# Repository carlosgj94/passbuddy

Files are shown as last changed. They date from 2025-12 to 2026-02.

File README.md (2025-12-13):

# Passbuddy — Hardware KeePass for ESP32-S3

Passbuddy is a no_std Rust firmware for the ESP32-S3 that acts like a USB keyboard (HID) to auto-type passwords stored in an on-device KeePass database. The database lives in flash and is encrypted with a software key derived from a user PIN plus the chip’s efuse keyslot 0 (unreadable externally), so secrets never leave the device.

## How It Works
- **Key derivation:** User PIN + IFUSE/HMAC using keyslot 0 → one-time KDF output (software key). The hardware root key never leaves the chip, and the PIN never leaves the device. The software key encrypts/decrypts the KeePass DB.
- **Usage model:** Plug the device; it enumerates as a USB keyboard. Enter PIN locally (buttons/rotary/etc). The DB decrypts on-device. When a login field is focused, the device types the selected password over USB keystrokes.
- **Security posture:** No cloud or sync. Flash theft is useless without the PIN and bypassing S3 anti-dump protections. Vendor compromise is irrelevant because secrets stay on hardware.

## Project Layout
- `src/bin/main.rs` — ESP-RTOS entrypoint; sets CPU clocks, HMAC peripheral, SPI2, and SSD1309 display; draws a simple `ratatui` list via `mousefood`; logs a heartbeat.
- `src/display.rs` — display helpers (`init_terminal`, `initial_state`, `draw_menu`).
- `src/display/ssd1309.rs` — SSD1309 SPI driver implementing `embedded-graphics` `DrawTarget` + framebuffer flush.
- `src/encryption.rs` — HMAC-based software key derivation (`derive_sw_key`).
- `build.rs` — adds linker scripts (`defmt.x`, `linkall.x`) and prints hints for missing symbols.
- `.cargo/config.toml` — targets `xtensa-esp32s3-none-elf`, sets `espflash` runner, enables `build-std` for `core`/`alloc`.

## Prereqs
- Rust toolchain channel `esp` (see `rust-toolchain.toml`); install Xtensa support via Espressif’s toolchain (e.g., `espup`).
- `espflash` installed and USB permissions set (dialout/uaccess on Linux).

## Build, Flash, and Dev
```bash
cargo build                 # dev build for ESP32-S3
cargo build --release       # size-optimized
cargo clippy --no-deps      # lint; keep warnings at zero
cargo run                   # flash + defmt monitor via espflash (device attached)
```
Notes: ensure only one serial/monitor session is open when flashing; replug USB if flashing stalls.

## Architecture Notes
- No_std + Embassy executor; heap set via `esp_alloc::heap_allocator!` in `main`.
- Display: SSD1309 over SPI2 (custom driver); UI rendered with `ratatui`/`mousefood`.
- HID keyboard output planned for password typing; input hardware for PIN entry is TBD.

## Status / Next Steps
- ✅ Display init and static menu render.
- ✅ Software key derivation helper using HMAC + RNG.
- ⏳ Implement PIN input, KeePass DB storage/crypto flow, HID keyboard typing, and runtime UI updates (via Embassy task).

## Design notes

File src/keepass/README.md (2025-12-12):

# KeePass v1 (KDB) File Format Reference

This document describes the full binary structure of a **KeePass v1 (.kdb)** database.  
It is tailored for implementors building parsers/writers (including embedded systems).

KeePass v1 is a flat, streaming binary format consisting of a plaintext header followed by an AES-encrypted payload containing groups and entries.

---

## 1. High-Level File Structure

```
+------------------------------+
|        HEADER (PLAINTEXT)    |
+------------------------------+
|     ENCRYPTED PAYLOAD        |
|     (AES-256-CBC)            |
|   +-----------------------+  |
|   | GROUP TABLE (N groups)|  |
|   +-----------------------+  |
|   | ENTRY TABLE (M entries)| |
|   +-----------------------+  |
|   | END MARKER             | |
|   +------------------------+ |
+------------------------------+
```

Groups and entries use the same TLV structure, but they appear in **separate sections**, and their counts are given in the header.

---

## 2. Header (Plaintext)

The header is unencrypted and always appears first.

```
MAGIC_1 (u32)               = 0x9AA2D903
MAGIC_2 (u32)               = 0xB54BFB66

VERSION (u32)               = (minor << 16 | major)
ENCRYPTION FLAGS (u32)
VERSION2 (u32)              = typically 0

MASTER SEED (16 bytes)
ENCRYPTION IV (16 bytes)

TRANSFORM SEED (32 bytes)
TRANSFORM ROUNDS (u32)

STREAM START BYTES (32 bytes)

GROUP COUNT (u32)           = number of groups N
ENTRY COUNT (u32)           = number of entries M
```

These counts determine how many groups and entries you must parse later.

---

## 3. Encrypted Payload (AES-256-CBC)

The payload is encrypted using:

```
AES_KEY = SHA256( master_seed || transformed_user_key )
```

Where `transformed_user_key` is produced by repeatedly encrypting the user key using AES-ECB for `TRANSFORM_ROUNDS`.

After decryption, the payload consists of:

```
[Group 1]
[Group 2]
...
[Group N]

[Entry 1]
[Entry 2]
...
[Entry M]

[Final End Marker]
```

---

## 4. TLV (Type-Length-Value) Encoding

Groups and entries share the same TLV encoding:

```
field_type : u16 (LE)
field_size : u32 (LE)
field_data : [field_size] bytes
```

Strings include a **null terminator** inside the field data.

Every group and entry ends with:

```
Type = 0xFFFF
Size = 0x00000000
```

---

## 5. Group Table (N Groups)

Parse **GroupCount** groups in order.

### Group Field Types

```
0x0001 → Group ID (u32)
0x0002 → Group Name (UTF-8, null-terminated)
0x0003 → Creation Time (packed time, 5 bytes)
0x0004 → Last Modification Time (packed time, 5 bytes)
0x0005 → Icon ID (u32)
0x0006 → Level (u16)
0xFFFF → End of Group
```

**Level** defines how groups are nested (indentation), not parent pointers.

---

## 6. Entry Table (M Entries)

After all groups are parsed, read **EntryCount** entries.

### Entry Field Types

```
0x0001 → UUID (16 bytes)
0x0002 → Group ID (u32)
0x0003 → Title (UTF-8, null-terminated)
0x0004 → Username (UTF-8)
0x0005 → Password (UTF-8)
0x0006 → URL (UTF-8)
0x0007 → Notes (UTF-8)

0x0008 → Creation Time (packed time, 5 bytes)
0x0009 → Last Modification Time (packed time, 5 bytes)
0x000A → Last Access Time (packed time, 5 bytes)
0x000B → Expiration Time (packed time, 5 bytes)
0x000C → Byte Description (UTF-8)
0x000D → Byte Data (raw bytes)

0xFFFF → End of Entry
```

Entries point to groups using `Group ID`.

---

## 7. End-of-Database Marker

After the last entry:

```
Type = 0xFFFF
Size = 0x00000000
```

This marker is required.

---

## 8. Parsing Procedure Summary

```
read header

for each group in 0..GroupCount:
    read TLV fields until type == 0xFFFF

for each entry in 0..EntryCount:
    read TLV fields until type == 0xFFFF

read final 0xFFFF database terminator
```

---

## 9. Notes for Implementors

- Group and entry TLV field types overlap; **context** (group section vs entry section) determines meaning.
- KeePass v1 stores timestamps as a packed 5-byte value (not Unix `time_t`).
- Strings are null-terminated inside the TLV binary.
- Adding or removing groups/entries requires rebuilding the entire payload; KDB is not a random-access format.

---

This reference is complete and suitable for building a KDB parser/writer from scratch.

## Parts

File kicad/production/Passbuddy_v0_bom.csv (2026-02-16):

Designator | Footprint | Quantity | Value | LCSC Part #
C1, C4, C5 | 0805 | 3 | 10uF 0805
C2 | 1206 | 1 | 22uF 1206
C3, C6 | 0402 | 2 | 100nF 0402
C7 | 0805 | 1 | 4.7uF 0805
D1, D2, D3 | 0603 | 3 | LED 0603 White
J1 | USB_C_Receptacle_HRO_TYPE-C-31-M-12 | 1 | USB_C_Receptacle_USB2.0_16P | C53207138
J2 | Tropic01_PinSocket | 1 | Conn_01x08_Socket
J3 | PinSocket_1x07_P2.54mm_Horizontal | 1 | Conn_01x07_Pin | C2897389
R1, R2, R3, R4, R5, R6 | 0402 | 6 | 5.1kΩ 0402
R7 | 0402 | 1 | 10kΩ 0402
S1 | XDCR_PEC11R-4220F-S0024 | 1 | PEC11R-4220F-S0024
SW2, SW3 | SW_SPST_B3U-1000P | 2 | SW_SPST | C720477
U1 | ESP32-S3-WROOM-1 | 1 | ESP32-S3-WROOM-1 | C2913202
U2 | SOT-223-3_TabPin2 | 1 | LD1117S33TR_SOT223 | C6186

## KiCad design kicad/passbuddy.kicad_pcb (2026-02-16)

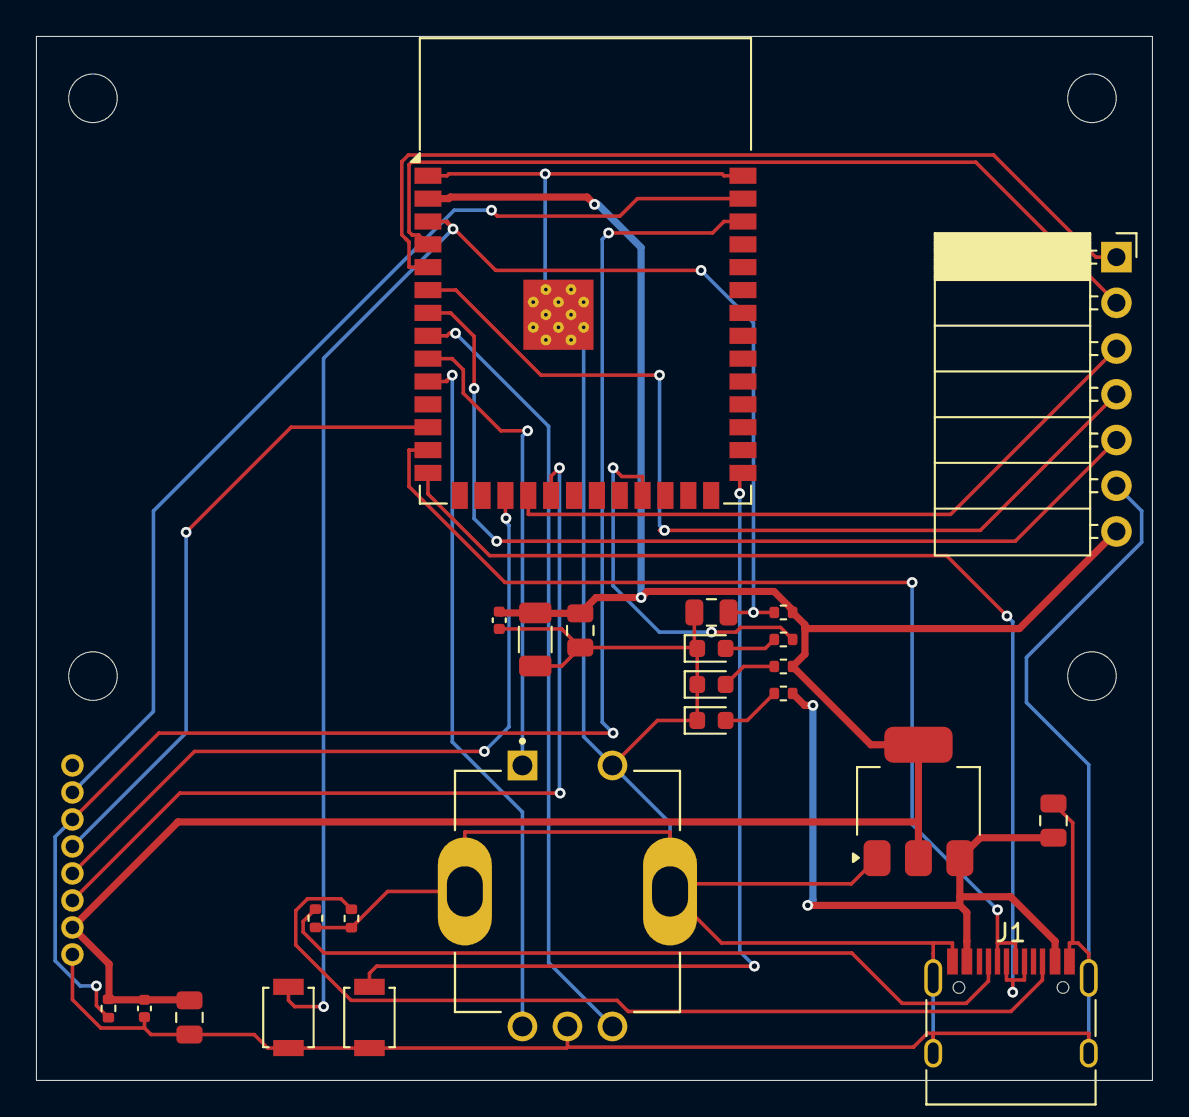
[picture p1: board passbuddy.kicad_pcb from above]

Board: 2 copper layers, 62.0 x 58.0 mm, 29 parts (0 on the bottom side), 26 nets.

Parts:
C1, C4, C5: 10uF 0805; C_0805_2012Metric
C2: 22uF 1206; C_1206_3216Metric
C3, C6: 100nF 0402; C_0402_1005Metric
C7: 4.7uF 0805; C_0805_2012Metric
D1, D2, D3: LED 0603 White; LED_0603_1608Metric
J1: USB_C_Receptacle_USB2.0_16P; USB_C_Receptacle_HRO_TYPE-C-31-M-12
J2: Conn_01x08_Socket; Tropic01_PinSocket
J3: Conn_01x07_Pin; PinSocket_1x07_P2.54mm_Horizontal
MountHole1, MountHole3, MountHole4: MountHole; MountingHole_2.7mm_M2.5
MountHole2: MountingHole_2.7mm_M2.5
R1, R2, R3, R4, R5, R6: 5.1kΩ 0402; R_0402_1005Metric
R7: 10kΩ 0402; R_0402_1005Metric
S1: PEC11R-4220F-S0024; XDCR_PEC11R-4220F-S0024
SW2, SW3: SW_SPST; SW_SPST_B3U-1000P
U1: ESP32-S3-WROOM-1
U2: LD1117S33TR_SOT223; SOT-223-3_TabPin2

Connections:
+3V3: C1.1, C2.1, C3.1, C6.1, C7.1, J2.7, J3.7, R4.2, R6.1, R7.2, U1.2 (3V3), U2.2 (VO)
+5V: C4.1, J1.A4 (VBUS), J1.A9 (VBUS), J1.B4 (VBUS), J1.B9 (VBUS), R5.1, U2.3 (VI)
CLK: J3.4, U1.6 (IO6)
CS: J3.3, U1.18 (IO10)
D+: J1.A6 (D+), J1.B6 (D+), U1.14 (USB_D+)
D-: J1.A7 (D-), J1.B7 (D-), U1.13 (USB_D-)
DC: J3.2, U1.4 (IO4)
DIN: J3.5, U1.7 (IO7)
EN: C5.1, R6.2, SW3.2 (B), U1.3 (EN)
GND: C1.2, C2.2, C3.2, C4.2, C5.2, C6.2, C7.2, D1.1 (K), D2.1 (K), D3.1 (K), J1.A1 (GND), J1.A12 (GND), J1.B1 (GND), J1.B12 (GND), J1.S1 (SHIELD), J2.8, J3.6, R1.2, R2.2, S1.2, S1.C (COM), S1.SH1 (SHIELD), S1.SH2 (SHIELD), SW2.1 (A), SW3.1 (A), U1.1 (GND), U1.40 (GND), U1.41 (GND), U2.1 (GND)
GPIO0: SW2.2 (B), U1.27 (IO0)
GPIO16: S1.1, U1.9 (IO16)
GPIO21: R3.1, U1.23 (IO21)
unnamed: D1.2 (A), R5.2
unnamed: D2.2 (A), R4.1
unnamed: D3.2 (A), R3.2
unnamed: J1.A5 (CC1), R1.1
unnamed: J1.B5 (CC2), R2.1
RST: J3.1, U1.5 (IO5)
RT_CLK: S1.A, U1.10 (IO17)
RT_DT: S1.B, U1.8 (IO15)
TROPIC_CLK: J2.4, U1.12 (IO8)
TROPIC_CS: J2.3, R7.1, U1.38 (IO2)
TROPIC_GPO: J2.2, U1.39 (IO1)
TROPIC_SDI: J2.6, U1.19 (IO11)
TROPIC_SDO: J2.5, U1.17 (IO9)

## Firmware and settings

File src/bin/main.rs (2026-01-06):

#![no_std]
#![no_main]
#![deny(
    clippy::mem_forget,
    reason = "mem::forget is generally not safe to do with esp_hal types, especially those \
    holding buffers for the duration of a data transfer."
)]

extern crate alloc;

mod usb_hid;

use defmt::info;
use embassy_executor::Spawner;
use embassy_time::{Duration, Timer};
use embedded_hal_bus::spi::ExclusiveDevice;
use esp_hal::delay::Delay;
use esp_hal::gpio::{Level, Output, OutputConfig};
use esp_hal::otg_fs::Usb;
use esp_hal::spi::{Mode as SpiMode, master::Config as SpiConfig, master::Spi};
use esp_hal::time::Rate;
use esp_hal::timer::timg::TimerGroup;
use esp_hal::{clock::CpuClock, hmac::Hmac};
use esp_storage::FlashStorage;
use passbuddy::app::AppState;
use passbuddy::keepass::KeePassDb;
use passbuddy::storage::layout::StorageLayout;
use passbuddy::storage::region::DataRegion;
use {esp_backtrace as _, esp_println as _};

use passbuddy::input::Inputs;
use passbuddy::{app, display};

// This creates a default app-descriptor required by the esp-idf bootloader.
// For more information see: <https://docs.espressif.com/projects/esp-idf/en/stable/esp32/api-reference/system/app_image_format.html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>
esp_bootloader_esp_idf::esp_app_desc!();

#[esp_rtos::main]
async fn main(spawner: Spawner) -> ! {
    // generator version: 1.0.1

    let config = esp_hal::Config::default().with_cpu_clock(CpuClock::max());
    let peripherals = esp_hal::init(config);

    esp_alloc::heap_allocator!(#[esp_hal::ram(reclaimed)] size: 73744);

    let timg0 = TimerGroup::new(peripherals.TIMG0);
    esp_rtos::start(timg0.timer0);

    info!("Embassy initialized!");

    // 1. Get the peripherals declared
    info!("Declared peripherals");
    let mut _hmac = Hmac::new(peripherals.HMAC);
    let spi = Spi::new(
        peripherals.SPI2,
        SpiConfig::default()
            .with_frequency(Rate::from_mhz(10))
            .with_mode(SpiMode::_0),
    )
    .unwrap()
    .with_sck(peripherals.GPIO6)
    .with_mosi(peripherals.GPIO7);
    let usb = Usb::new(peripherals.USB0, peripherals.GPIO20, peripherals.GPIO19);

    // 2. Let's initialize the display
    info!("Initializing display");
    let cs = Output::new(peripherals.GPIO10, Level::High, OutputConfig::default());
    let dc = Output::new(peripherals.GPIO4, Level::Low, OutputConfig::default());
    let reset = Output::new(peripherals.GPIO5, Level::High, OutputConfig::default());

    let spi_dev = ExclusiveDevice::new_no_delay(spi, cs).unwrap();
    let interface = display::ssd1309::SpiInterface::new(spi_dev, dc);
    let mut display = display::ssd1309::Ssd1309::new(interface, Some(reset));

    display
        .init(&mut Delay::new())
        .unwrap_or_else(|_| panic!("SSD1309 init failed"));

    let app_state = AppState::new();
    let mut terminal = app::init_terminal_with_flush(&mut display, |display| {
        display
            .flush()
            .unwrap_or_else(|_| panic!("SSD1309 flush failed"));
    });

    // 4. Let's initialize the storage
    info!("Initializing storage");
    let mut storage = FlashStorage::new(peripherals.FLASH);

    // Debug helper: wipe the storage layout sector. If enabled, keep it *before*
    // `run_healthcheck()` so the layout gets bootstrapped again.
    // StorageLayout::wipe_layout(&mut storage).unwrap();

    match StorageLayout::run_healthcheck(&mut storage) {
        Ok(_) => {
            info!("Storage found; good to read");
        }
        Err(_) => {
            // The decive needs to be writen
            info!("Storage not found; initializing");
            StorageLayout::bootstrap_storage_write(&mut storage)
                .expect("initial storage bootstraping error");
        }
    }

    let layout = StorageLayout::new(&mut storage);
    let magic_str = core::str::from_utf8(&layout.header.magic).unwrap_or("<invalid utf8>");
    info!("magic: {=str}", magic_str);

    // 5. Let's initialize the input devices
    info!("Setting the inputs");
    let mut inputs = Inputs::new(peripherals.GPIO17, peripherals.GPIO15, peripherals.GPIO16);
    //
    // 6. Get the key to decrypt the storage
    //
    // 7. Get the keepass groups
    let keepass_region = layout.region_handle(DataRegion::KeePassDb).unwrap();
    if !KeePassDb::check_if_exists(&mut storage, keepass_region).unwrap() {
        info!("Creating a new keepass");
        KeePassDb::initialize_db(&mut storage, keepass_region).unwrap();
    }

    info!("Indexing the keepass database");
    let kpdb = KeePassDb::new(&mut storage, keepass_region).unwrap();
    let mut app_state = app_state.with_kpdb(kpdb);

    usb_hid::spawn(&spawner, usb);

    info!("Starting the loop");
    const INPUT_TICK_MS: u64 = 2;
    const UI_TICK_MS: u64 = 50;
    let mut ui_elapsed_ms = 0u64;

    loop {
        Timer::after(Duration::from_millis(INPUT_TICK_MS)).await;
        let delta = inputs.poll_encoder_delta();
        if delta != 0 {
            app_state.apply_navigation(delta);
        }

        ui_elapsed_ms = ui_elapsed_ms.saturating_add(INPUT_TICK_MS);
        if ui_elapsed_ms >= UI_TICK_MS {
            ui_elapsed_ms = ui_elapsed_ms.saturating_sub(UI_TICK_MS);
            app_state.apply_navigation(0);

            if inputs.poll_button_pressed() {
                info!("Action button pressed");
                app_state.on_select(&mut storage);
            }

            app_state.on_tick(&mut storage);

            terminal
                .draw(|frame| app_state.draw_current_screen(frame))
                .expect("to draw");
        }
    }
}

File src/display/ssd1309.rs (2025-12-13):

use core::convert::Infallible;

use embedded_graphics::{
    geometry::Size,
    pixelcolor::BinaryColor,
    prelude::{DrawTarget, OriginDimensions, Pixel},
};
use embedded_hal::{delay::DelayNs, digital::OutputPin, spi::SpiDevice};

const WIDTH: usize = 128;
const HEIGHT: usize = 64;
const PAGES: usize = HEIGHT / 8;
const BUFFER_SIZE: usize = WIDTH * PAGES;

pub trait DisplayInterface {
    type Error;

    fn send_commands(&mut self, cmds: &[u8]) -> Result<(), Self::Error>;
    fn send_data(&mut self, data: &[u8]) -> Result<(), Self::Error>;
}

pub enum InterfaceError<SpiError, PinError> {
    Spi(SpiError),
    Pin(PinError),
}

pub struct SpiInterface<SPI, DC> {
    spi: SPI,
    dc: DC,
}

impl<SPI, DC> SpiInterface<SPI, DC> {
    pub fn new(spi: SPI, dc: DC) -> Self {
        Self { spi, dc }
    }

    pub fn release(self) -> (SPI, DC) {
        (self.spi, self.dc)
    }
}

impl<SPI, DC> DisplayInterface for SpiInterface<SPI, DC>
where
    SPI: SpiDevice<u8>,
    DC: OutputPin,
{
    type Error = InterfaceError<SPI::Error, DC::Error>;

    fn send_commands(&mut self, cmds: &[u8]) -> Result<(), Self::Error> {
        self.dc.set_low().map_err(InterfaceError::Pin)?;
        self.spi.write(cmds).map_err(InterfaceError::Spi)
    }

    fn send_data(&mut self, data: &[u8]) -> Result<(), Self::Error> {
        self.dc.set_high().map_err(InterfaceError::Pin)?;
        self.spi.write(data).map_err(InterfaceError::Spi)
    }
}

#[derive(Clone, Copy)]
pub enum Rotation {
    Rotate0,
    Rotate180,
}

#[derive(Clone, Copy)]
pub enum VccMode {
    /// Uses `0xAD 0x8A` in the init sequence.
    External,
    /// Uses `0xAD 0x8B` in the init sequence.
    Internal,
}

pub struct Config {
    pub rotation: Rotation,
    pub vcc_mode: VccMode,
    pub column_offset: u8,
    pub contrast: u8,
    pub inverted: bool,
}

impl Default for Config {
    fn default() -> Self {
        Self {
            rotation: Rotation::Rotate0,
            vcc_mode: VccMode::Internal,
            column_offset: 0,
            contrast: 0x7F,
            inverted: false,
        }
    }
}

pub enum Error<InterfaceError, ResetError> {
    Interface(InterfaceError),
    Reset(ResetError),
}

pub struct Ssd1309<IF, RST> {
    iface: IF,
    reset: Option<RST>,
    buffer: [u8; BUFFER_SIZE],
    config: Config,
}

impl<IF, RST> Ssd1309<IF, RST> {
    pub fn new(iface: IF, reset: Option<RST>) -> Self {
        Self {
            iface,
            reset,
            buffer: [0; BUFFER_SIZE],
            config: Config::default(),
        }
    }

    pub fn with_config(mut self, config: Config) -> Self {
        self.config = config;
        self
    }

    pub fn release(self) -> (IF, Option<RST>) {
        (self.iface, self.reset)
    }

    pub fn flush(&mut self) -> Result<(), Error<IF::Error, RST::Error>>
    where
        IF: DisplayInterface,
        RST: OutputPin,
    {
        let col = self.config.column_offset;
        let buffer = &self.buffer;
        let iface = &mut self.iface;

        for page in 0..PAGES {
            let page_cmd = 0xB0u8 | page as u8;
            let col_low = col & 0x0F;
            let col_high = 0x10 | (col >> 4);

            iface
                .send_commands(&[page_cmd, col_low, col_high])
                .map_err(Error::Interface)?;

            let start = page * WIDTH;
            let end = start + WIDTH;
            iface
                .send_data(&buffer[start..end])
                .map_err(Error::Interface)?;
        }

        Ok(())
    }

    pub fn init(&mut self, delay: &mut impl DelayNs) -> Result<(), Error<IF::Error, RST::Error>>
    where
        IF: DisplayInterface,
        RST: OutputPin,
    {
        if let Some(reset) = self.reset.as_mut() {
            reset.set_low().map_err(Error::Reset)?;
            delay.delay_ms(10);
            reset.set_high().map_err(Error::Reset)?;
            delay.delay_ms(10);
        }

        let (seg_remap, com_scan) = match self.config.rotation {
            Rotation::Rotate0 => (0xA1, 0xC8),
            Rotation::Rotate180 => (0xA0, 0xC0),
        };

        let dc_dc = match self.config.vcc_mode {
            VccMode::External => 0x8A,
            VccMode::Internal => 0x8B,
        };

        let invert = if self.config.inverted { 0xA7 } else { 0xA6 };

        self.send_commands(&[
            0xAE, // Display off
            0xD5,
            0x80, // Clock divide ratio
            0xA8,
            0x3F, // Multiplex ratio (1/64)
            0xD3,
            0x00, // Display offset
            0x40, // Display start line
            0xAD,
            dc_dc,     // DC-DC control
            seg_remap, // Segment remap
            com_scan,  // COM scan direction
            0xDA,
            0x12, // COM pins config
            0x81,
            self.config.contrast, // Contrast
            0xD9,
            0x22, // Pre-charge period
            0xDB,
            0x20,   // VCOMH deselect level
            0xA4,   // Resume to RAM content display
            invert, // Normal/invert display
            0x20,
            0x02, // Page addressing mode
            0x2E, // Deactivate scroll
            0xAF, // Display on
        ])?;

        self.clear_buffer(BinaryColor::Off);
        self.flush()?;

        Ok(())
    }

    pub fn clear_buffer(&mut self, color: BinaryColor) {
        self.buffer.fill(if color.is_on() { 0xFF } else { 0x00 });
    }

    fn send_commands(&mut self, cmds: &[u8]) -> Result<(), Error<IF::Error, RST::Error>>
    where
        IF: DisplayInterface,
        RST: OutputPin,
    {
        self.iface.send_commands(cmds).map_err(Error::Interface)
    }
}

impl<IF, RST> OriginDimensions for Ssd1309<IF, RST> {
    fn size(&self) -> Size {
        Size::new(WIDTH as u32, HEIGHT as u32)
    }
}

impl<IF, RST> DrawTarget for Ssd1309<IF, RST> {
    type Color = BinaryColor;
    type Error = Infallible;

    fn draw_iter<I>(&mut self, pixels: I) -> Result<(), Self::Error>
    where
        I: IntoIterator<Item = Pixel<Self::Color>>,
    {
        for Pixel(point, color) in pixels.into_iter() {
            if point.x < 0 || point.y < 0 {
                continue;
            }

            let x = point.x as usize;
            let y = point.y as usize;

            if x >= WIDTH || y >= HEIGHT {
                continue;
            }

            let page = y / 8;
            let bit = y % 8;
            let index = page * WIDTH + x;
            let mask = 1u8 << bit;

            if color.is_on() {
                self.buffer[index] |= mask;
            } else {
                self.buffer[index] &= !mask;
            }
        }

        Ok(())
    }

    fn clear(&mut self, color: Self::Color) -> Result<(), Self::Error> {
        self.clear_buffer(color);
        Ok(())
    }
}

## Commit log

2025-12-11 feat: adding the dma helper for usage on the key generation
2025-12-12 chore: adding logs to check the OS is working correctly
    [main.rs]
2025-12-12 fix: avoiding busy spining
    [main.rs]
2025-12-13 fix: removing the long ass vec
    [main.rs]
2025-12-13 feat: adding the ssd1309 driver and hooking it up to the tui
2025-12-13 feat: refactoring a bit the ui and creating the action button in the inputs
2025-12-16 fix: offset layout and various errors preventing initialization
    [main.rs]
2025-12-16 feat: improving the button responsiveness
2025-12-17 feat: swapping the potentiometer and the button for a rotatory navigator
    [input.rs, main.rs]
2025-12-17 fix: creating entries in many groups
    [main.rs]
2026-01-06 feat: removing the option to add a pin to the group
2026-01-06 feat: adding the screeen to input the pin
2026-02-16 feat: adding the kicad files
    [Passbuddy_v0_bom.csv, Passbuddy_v0_designators.csv, Passbuddy_v0_positions.csv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]
